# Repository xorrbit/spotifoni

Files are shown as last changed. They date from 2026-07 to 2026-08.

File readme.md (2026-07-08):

# Spotifoni

Marconi 378 antique console radio converted into a Spotify Connect speaker and Bluetooth audio sink, powered by a Raspberry Pi 3B.

## Hardware

- Raspberry Pi 3 Model B V1.2
- MAX98357A I2S mono amplifier
- Visaton FR 10 HM 4Ω full-range speaker
- 4× KY-040 rotary encoders (volume, previous, play/pause, next)
- WS2812B RGB LED sticks (8 LEDs each, behind tuner window)
- 74AHCT125 level shifter for LED data signal

See [design.md](design.md) for the full design document and [wiring.md](wiring.md) for the wiring diagrams.

## Setup

### Prerequisites

Flash **Raspberry Pi OS Lite (64-bit, Bookworm)** to a microSD card using the Raspberry Pi Imager. In the imager settings, configure:
- WiFi credentials
- SSH enabled
- Username and password

### Provision

SSH into the Pi and update the system:

```bash
sudo apt update
sudo apt upgrade -y
sudo apt install -y git
```

Clone the repo and run the setup script:

```bash
git clone https://github.com/xorrbit/spotifoni.git
cd spotifoni
sudo ./setup.sh
```

This installs all dependencies (raspotify, BlueZ, Python packages), deploys the application to `/opt/spotifoni`, configures I2S audio output, sets the hostname to `spotifoni`, and enables all systemd services.

Reboot after first run (required for the I2S DAC overlay):

```bash
sudo reboot
```

### Deploy Updates

After making changes on your dev machine, push them to the Pi without re-running the full setup:

```bash
./deploy.sh              # defaults to spotifoni.local
./deploy.sh 192.168.1.50 # or specify a host
```

This rsyncs the GPIO daemon and web app to the Pi and restarts both services.

## Usage

| What | Where |
|---|---|
| Spotify Connect | Open Spotify on any device, select **Marconi 378** as the playback device |
| Bluetooth | Pair your phone with **spotifoni** via Bluetooth settings |
| Web UI | `http://spotifoni.local/` — service status, volume, Bluetooth devices, system controls |
| SSH | `ssh pi@spotifoni.local` |

### Standalone Playback (without a phone)

Requires a Spotify Premium account.

1. Create a Spotify Developer App at https://developer.spotify.com/dashboard
2. Add `http://spotifoni.local/api/spotify/callback` as a redirect URI
3. Copy `config/spotify_api.json.example` to `config/spotify_api.json` and fill in `client_id` and `client_secret`
4. Deploy to the Pi (`./deploy.sh`)
5. Open `http://spotifoni.local/` and click **Connect Spotify Account**
6. Log in with your Spotify Premium account and authorize
7. Connect to **Marconi 378** once from any Spotify app (phone, desktop, or web player) to register the device with your account

After setup, paste any Spotify playlist, album, or track URL into the **Standalone Playback** card and press **Play**. No phone needed.

> **Tip:** To skip step 7, add `LIBRESPOT_USERNAME` and `LIBRESPOT_PASSWORD` to `/etc/raspotify/conf`. This makes the device register with Spotify automatically on boot.

### Physical Controls

- **Volume dial** — rotate to adjust volume, press to toggle mute
- **Previous dial** — press for previous track
- **Play/Pause dial** — press to toggle playback
- **Next dial** — press for next track

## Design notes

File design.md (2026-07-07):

# Spotifoni - Antique Radio Modernization — Design Document

## Project Summary

Convert a Marconi 378 antique console radio into a modern streaming audio device while preserving the original exterior appearance. The unit will support Spotify Connect (appearing as a castable speaker in the Spotify app) and function as a Bluetooth speaker for any paired phone. The four original dials will be retrofitted with rotary encoders to provide physical controls for volume, transport, and power. Configuration will happen through a local web interface.

## Design Philosophy

The guiding principle is "invisible modernity." From the outside, this should look and feel like an untouched Marconi 378. Every component choice favors small footprint, low heat, and silence. The internal layout should be tidy enough that if someone opens the back, it looks intentional — not a rat's nest.

## Hardware Architecture

### Computing Platform — Raspberry Pi 3 Model B V1.2

The brain of the system is an existing Raspberry Pi 3 Model B V1.2. It has a quad-core Cortex-A53 at 1.2 GHz, 1 GB of RAM, 2.4 GHz WiFi, and Bluetooth Classic 4.1 with A2DP support — all built in. The 40-pin GPIO header provides I2S audio output and enough GPIO pins for four rotary encoders and the WS2812 LED display. The board runs headless Raspberry Pi OS Lite with no issues.

1 GB of RAM is more than enough for the Spotify Connect + Bluetooth workload. Only a heavier approach like running a full desktop browser in kiosk mode would strain it, and that's unlikely to be needed.

The board is credit-card sized (85×56 mm), which is larger than a Pi Zero but trivially small relative to the Marconi 378's console cabinet. It draws roughly 1.5–2.5W under typical load. A passive heatsink is a good idea inside the enclosed cabinet but active cooling is not needed at these workloads.

### Audio Output — MAX98357A I2S Mono Amp

The MAX98357A breakout board takes I2S digital audio directly from the Pi's GPIO header and outputs up to 3.2W into a 4Ω speaker. The signal stays digital all the way to the amplifier chip, avoiding the Pi's noisy built-in PWM audio jack entirely. The board is tiny (roughly 25×20 mm), needs no external components, and solders to five GPIO pins: LRCLK (GPIO 19), BCLK (GPIO 18), DIN (GPIO 21), VIN (5V), and GND.

At 3.2W into the 4Ω Visaton FR 10 HM, the system will produce approximately 90 dB SPL at one meter — more than enough to fill a living room from a console radio.

### Speaker — Visaton FR 10 HM, 4Ω

The original Marconi 378 speaker is an electro-dynamic field-coil loudspeaker with a 3.2Ω voice coil. Field-coil speakers require a separate DC power supply (typically 50–100+ volts) to energize the electromagnet — without it the speaker is completely dead. Rather than rebuilding that high-voltage supply chain, the original speaker is being replaced with a modern permanent magnet driver.

The Visaton FR 10 HM is a 4-inch (10 cm) full-range driver, 4Ω impedance, rated at 20W (max 30W). It has a paper cone with moisture-resistant coating and a small whizzer tweeter cone for extended high-frequency response (95 Hz – 22 kHz). Sensitivity is 85 dB at 1W/1m. The paper cone construction gives it a warm, natural character well-suited to the "antique radio playing modern music" aesthetic.

The Marconi 378's original speaker opening is significantly larger than 4 inches. An adapter ring (flat plywood, MDF, or 3D-printed ring) with the large outer diameter matching the cabinet's existing mounting holes and a smaller inner cutout for the FR 10 HM will be fabricated. Painted black, it disappears behind the grille cloth.

The original field-coil speaker will be preserved and stored.

### Controls — KY-040 Rotary Encoders

Each of the four original dials will be mechanically coupled to a KY-040 incremental rotary encoder with a built-in push button. These output two quadrature signals (A and B channels) for rotation direction, plus a momentary switch signal when pressed. The KY-040 breakout boards include pull-up resistors, which simplifies wiring.

The mechanical coupling to the original dial shafts is the trickiest physical part of the build. Options include a flexible shaft coupler if the diameters match, a 3D-printed adapter sleeve, or mounting the encoder directly behind the dial and using a short section of silicone tubing as a flexible coupler. Standard encoder shafts are 6mm D-shaft; if the original dials are friction-fit, they may press directly onto the encoder shaft.

Control mapping:

Dial 1 (Volume): Rotate for volume up/down. Press to toggle mute or power standby. A dedicated toggle switch on the back panel for hard power on/off is the simpler alternative.

Dial 2 (Previous): Press to go to the previous track. Rotation can be mapped to seeking backward within a track, or left unmapped initially.

Dial 3 (Play/Pause): Press to toggle playback. Rotation can be mapped to switching between Spotify and Bluetooth input sources, or left unmapped initially.

Dial 4 (Next): Press to skip to the next track. Rotation can be mapped to seeking forward, or left unmapped initially.

Each encoder uses 3 GPIO pins (A, B, and switch), so four encoders need 12 GPIO pins. The Pi 3B has 26 usable GPIO pins, leaving room for the I2S bus (3 pins) and SPI for the WS2812 display (5 pins, of which only MOSI is wired).

### Status Display — WS2812B RGB LED Sticks

The tuner window is fitted with WS2812B 5050 RGB LED sticks (8 addressable LEDs per stick, chainable). These replace the original plan for individual status LEDs and provide a far more expressive display — color, brightness, and animation can all be controlled per-pixel from software.

The WS2812B protocol requires a single data line with precise timing. The Pi's SPI0 MOSI (GPIO 10) drives the data through a 74AHCT125 level shifter, which converts the Pi's 3.3V output to the 5V logic the LEDs expect. A 470Ω resistor on the data line between the level shifter output and the first LED's DIN pin prevents signal reflections. A 1000µF electrolytic capacitor across the LED power input absorbs inrush current when the LEDs switch on.

The LED sticks are powered from the same 5V rail as the rest of the system, via a separate power wire run (not through the Pi's GPIO header). At full white, 8 LEDs draw approximately 480mA; in practice, the display will run at reduced brightness and rarely approach this. The Mean Well IRM-15-5 PSU has sufficient headroom. For larger chains, a dedicated 5V supply is recommended.

The `rpi_ws281x` Python library drives the LEDs via the SPI backend. SPI0 is enabled in `/boot/firmware/config.txt`. The SPI driver claims GPIO 7, 8, 9, 10, and 11; only GPIO 10 (MOSI) is wired.

### Power Supply

The Pi 3B draws up to 2.5W under load. The MAX98357A at full volume adds up to 3.2W. LEDs and encoders add negligible draw. Total worst-case system draw is roughly 8W, so a 5V/2.5A (12.5W) supply has comfortable margin.

A Mean Well IRM-15-5 (5V, 3A, 15W) or similar enclosed AC-DC module takes mains AC directly and outputs regulated 5V. It's compact, efficient, and designed to be built into equipment. Wire the radio's power cord to the AC input side. Add a fuse (1A slow-blow) on the mains input for safety.

The original radio's power cord should be replaced with a modern 3-prong grounded cord if the chassis is metal, or at minimum a polarized 2-prong cord. Old ungrounded cloth cords are a fire and shock hazard. An IEC C14 panel-mount inlet on the back panel is the cleanest approach — it looks professional and lets you use any standard computer power cord.

## Software Architecture

The entire software stack runs on Raspberry Pi OS Lite (64-bit, Bookworm), the headless, no-desktop variant. Everything is managed through systemd services and configured either by editing files over SSH or through the web interface.

### Operating System Setup

Flash Raspberry Pi OS Lite (64-bit) to a microSD card using the Raspberry Pi Imager. Pre-configure WiFi credentials (hardcoded for now) and enable SSH in the imager's settings before first boot. On first boot the Pi will connect to the network and be accessible via SSH. No monitor or keyboard needed at any point.

### Spotify Connect — raspotify

The `raspotify` package wraps librespot (an open-source Spotify Connect client written in Rust) into a Debian package with a systemd service. Install it, configure the audio backend to use the I2S DAC via ALSA, and it just works. The radio will appear as a named device (e.g., "Marconi 378") in the Spotify app on any phone or computer on the same network. Configuration lives in `/etc/raspotify/conf` — device name, audio backend, bitrate (320 kbps for premium accounts), initial volume, and normalization settings.

Raspotify also exposes playback events (track change, play, pause, volume change) that the control daemon can subscribe to for updating the LED display.

### Bluetooth A2DP Sink

The Pi 3B's built-in Bluetooth 4.1 radio, managed by BlueZ, acts as an A2DP audio sink (a Bluetooth speaker). The setup involves enabling the Bluetooth service, setting the Pi as discoverable and pairable, configuring an agent that auto-accepts pairing, and routing the Bluetooth audio through PipeWire to the same ALSA output as Spotify.

PipeWire handles the audio routing — it can mix multiple sources and switch between them. When Spotify Connect is active, it plays Spotify. When a phone connects via Bluetooth and plays audio, it plays that instead (or mixes, depending on configuration). Priority can be configured so Spotify Connect takes over when activated, or vice versa.

Auto-pairing with a trusted device list means pairing a phone once, and it reconnects automatically whenever the radio is powered on and the phone is in range.

### GPIO Control Daemon

A small Python service using `gpiozero`. The daemon:

Reads the four rotary encoders and their push buttons via interrupts (not polling — important for responsiveness and low CPU usage). Translates encoder rotation into volume commands via `amixer` or PipeWire's `wpctl` for the volume dial. Translates button presses into MPRIS2 D-Bus commands for play/pause/next/previous — MPRIS2 is the standard Linux media player interface, and both raspotify and the Bluetooth audio player expose it, so the same button commands control whichever source is active. Drives the WS2812B RGB LED display behind the tuner window via the `rpi_ws281x` library over SPI.

This daemon runs as a systemd service that starts on boot.

### Web Configuration Interface

A lightweight Flask (Python) web server running on port 80. Accessible from any browser on the local network at `http://spotifoni.local/` (via mDNS/Avahi). It provides WiFi configuration (scan for networks, enter credentials, save to wpa_supplicant or NetworkManager), Spotify device name and audio settings, Bluetooth pairing management (list paired devices, remove pairings, toggle discoverability), system controls (restart services, reboot, shutdown safely), and a volume slider and transport controls as a web remote.

This can be very bare-bones — even a single page with a few forms. It grows naturally as features are added.

### Power Management

The Pi doesn't have a true hardware power switch — when power is cut, it just dies, which can corrupt the SD card over time. The simplest safe approach is to configure the filesystem as read-only using `overlayfs`. The root filesystem is mounted as a read-only overlay, with a writable tmpfs layer for runtime state. Configuration changes (via the web UI) temporarily remount the persistent layer as writable, write the change, and remount read-only. This is the standard approach for embedded Pi projects.

With a read-only filesystem, the back-panel power switch can just cut power directly. No shutdown sequence needed. The Pi 3B boots in about 15–20 seconds.

## Bill of Materials

| Component | Status | Approximate Cost |
|---|---|---|
| Raspberry Pi 3 Model B V1.2 | On hand | $0 |
| MAX98357A I2S Amp Breakout | Ordered | ~$6 |
| 4× KY-040 Rotary Encoders | Ordered | ~$6 |
| Visaton FR 10 HM, 4Ω | Ordered | ~$15 |
| Mean Well IRM-15-5 (5V 3A PSU) | To order | ~$10 |
| WS2812B 5050 RGB LED sticks (8 LEDs each) | Ordered | ~$4 |
| 74AHCT125 level shifter | To order | ~$2 |
| 1000µF electrolytic capacitor | To order | ~$1 |
| MicroSD card (32 GB) | To order | ~$6 |
| IEC C14 power inlet | To order | ~$3 |
| Fuse holder + 1A slow-blow fuse | To order | ~$2 |
| Speaker adapter ring material (plywood/MDF) | To fabricate | ~$3 |
| Hook-up wire, connectors, standoffs, heat shrink | To order | ~$8 |

**Total: approximately $65 CAD** (less if parts are on hand; Pi is free since it's existing stock).

## Physical Integration Plan

Strip the Marconi 378's original internals (tube chassis, original transformer, original wiring). Preserve the original field-coil speaker, the dial mechanisms, and all decorative elements. Document everything with photos before removing — reference original mounting positions.

Mount the Pi and amp board to a small piece of acrylic, plywood, or 3D-printed bracket that attaches to existing screw holes or standoffs inside the cabinet. Keep the microSD card slot accessible for reflashing.

Fabricate the speaker adapter ring: measure the original speaker cutout diameter, cut a ring from plywood or MDF with that outer diameter and a 4-inch (100mm) inner cutout for the FR 10 HM. Drill mounting holes for both the cabinet and the new speaker. Paint black.

Mount the rotary encoders behind the original dial positions. Measure the original shaft diameters and spacing, fabricate adapter couplers (3D-printed sleeves, flexible shaft couplers, or silicone tubing). If the original dials are friction-fit, they may press directly onto the 6mm encoder D-shafts.

Run the power cord through the original cord entry point. Mount the IEC C14 inlet on the back panel. Position the PSU module away from the audio components to minimize electrical noise.

Route wiring neatly with zip ties or cable lacing. Keep mains AC wiring physically separated from low-voltage DC signal wiring. Use JST connectors for serviceability so components can be disconnected without desoldering.

## Build Roadmap

**Bench validation** — Get the Pi 3B running headless with SSH access. Install raspotify, confirm Spotify Connect works with the FR 10 HM connected via the MAX98357A. Set up Bluetooth A2DP sink and confirm phone audio plays through the same output. Wire up all four encoders and the WS2812B LED display on a breadboard. Write the full GPIO control daemon with MPRIS2 integration. Set up PipeWire for audio source switching. Build the basic web config interface. Configure read-only filesystem.

**Physical integration** — Strip the radio. Fabricate the speaker adapter ring and encoder mounts. Build the internal component bracket. Transfer everything from the breadboard into the cabinet. Solder permanent connections or crimp JST connectors. Test everything in-cabinet, adjust LED brightness and encoder feel.

**Polish** — Tune the audio (EQ settings in PipeWire to compensate for the speaker and cabinet characteristics). Refine the web interface. Set up mDNS so the web UI is reachable at `marconi378.local`. Final cable management and cleanup.

## Future Upgrades

### Standalone Spotify (Software Only)

When ready to move beyond Spotify Connect to fully standalone playback (power on, press play, music plays without touching a phone), the hardware is already in place. Replace raspotify with `spotifyd`, which is a more feature-rich Spotify client that can be controlled programmatically. Write a control layer that uses the Spotify Web API (with an OAuth token stored on the device) to manage playback — load a saved playlist, resume last session, skip tracks. The rotary encoders gain new roles: one dial scrolls through playlists, another navigates tracks within a playlist. An SSD1306 OLED displays track info and playlist names. A phone is only needed for the initial OAuth login. The Pi 3B's 1 GB of RAM handles this comfortably.

### Board Swap

If more compute power is ever needed (unlikely for audio), the Pi 3B can be swapped for a Pi 4B or Pi 5 with no other hardware changes — same 40-pin GPIO header, same I2S pinout, same software stack. For an open-source hardware path, the BeaglePlay ($99, OSHW-certified, 2 GB RAM, 16 GB eMMC) is the strongest alternative, though it requires a USB Bluetooth dongle for A2DP since it only has BLE onboard.

### Audio Quality Upgrade

If the MAX98357A's audio quality ever feels limiting, swap it for a PCM5102A I2S DAC breakout (line-level output) feeding a separate higher-quality amplifier. The I2S pins on the Pi are the same, so it's a drop-in change on the digital side.

### Original Speaker Restoration

The Marconi 378's field-coil speaker could be brought back to life by building a DC power supply for the field coil (measure its resistance, provide appropriate voltage and current) and adding a 1Ω series resistor to bring the 3.2Ω voice coil impedance up to 4.2Ω for the MAX98357A. This is a rewarding side project for a rainy weekend but not required for the system to work.

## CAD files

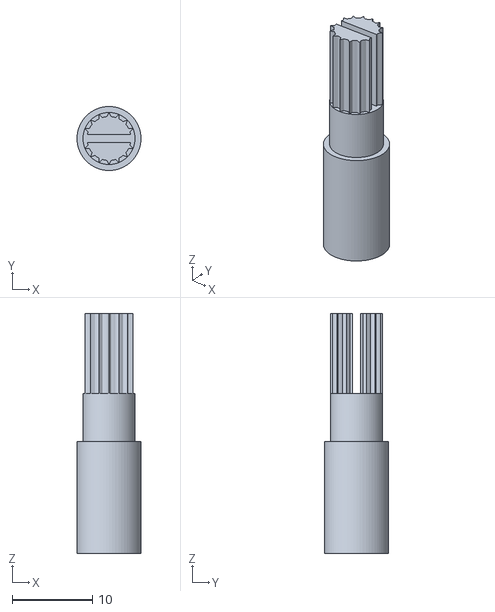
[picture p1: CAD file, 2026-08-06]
knob extender v3.stl
8.00 x 8.00 x 30.0

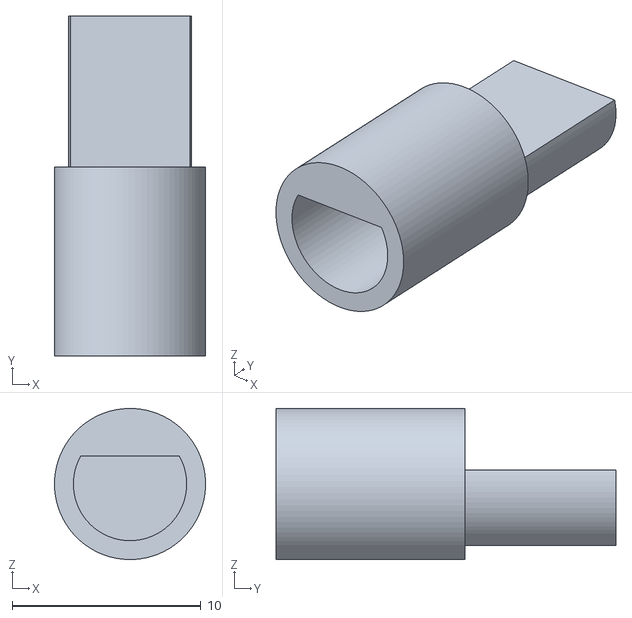
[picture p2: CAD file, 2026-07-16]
rotary encoder knob adapter.stl
8.00 x 18.0 x 8.00

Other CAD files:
knob extender v2.stl
knob extender.stl

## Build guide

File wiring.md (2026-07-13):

# Spotifoni Wiring

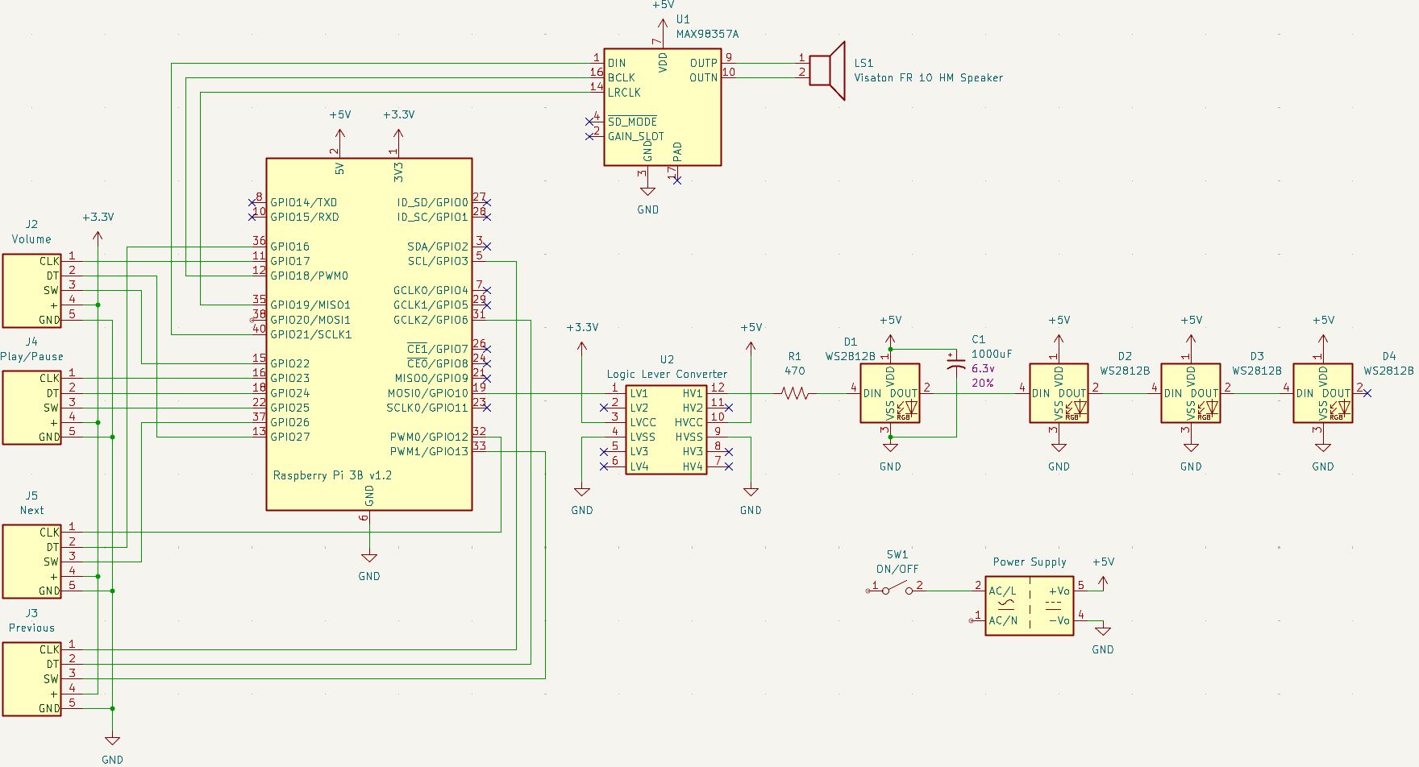
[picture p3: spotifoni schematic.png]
Schematic


## GPIO Allocation

| Function | GPIO Pins | Header Pins |
|---|---|---|
| Encoder 1 — Volume | GPIO 17, 27, 22 | 11, 13, 15 |
| Encoder 2 — Previous | GPIO 5, 6, 13 | 29, 31, 33 |
| Encoder 3 — Play/Pause | GPIO 23, 24, 25 | 16, 18, 22 |
| Encoder 4 — Next | GPIO 12, 16, 26 | 32, 36, 37 |
| WS2812B LED data | GPIO 10 | 19 |
| SPI0 (reserved by driver) | GPIO 7, 8, 9, 11 | 26, 24, 21, 23 |
| *I²S bus (allocated)* | GPIO 18, 19, 21 | 12, 35, 40 |

## I²S Amplifier (U1 — MAX98357A)

| Pi Header | Function | MAX98357A |
|---|---|---|
| Pin 2 | 5V Power | VDD |
| Pin 6 | Ground | GND |
| Pin 12 | GPIO 18 · PCM_CLK | BCLK |
| Pin 35 | GPIO 19 · PCM_FS | LRCLK |
| Pin 40 | GPIO 21 · PCM_DOUT | DIN |

Speaker output (OUTP/OUTN) connects to a Visaton FR 10 HM 8Ω speaker.

## WS2812B LED Display (D1–D4)

The LED data signal passes through a logic level converter (U2) to shift GPIO 10's 3.3V output to 5V. A 1kΩ resistor (R1) sits between the level converter output and the first LED's DIN pin.

| From | To | Notes |
|---|---|---|
| Pi GPIO 10 (Pin 19) | U2 LV1 (pin 1) | 3.3V data from SPI MOSI |
| U2 HV1 (pin 12) | R1 (470Ω) → D1 WS2812B DIN | 5V level-shifted data out |
| Pi 3.3V (Pin 1) | U2 LVCC (pin 3) | Level converter low-side supply |
| 5V rail | U2 HVCC (pin 9) | Level converter high-side supply |
| GND | U2 LVSS (pin 5), U2 HVSS (pin 4) | Common ground |
| 5V rail | C1 1000µF cap (+) → D1 VDD | Bulk decoupling for LED chain |
| GND | C1 1000µF cap (−) → D1 VSS | |

LEDs are daisy-chained: D1 DOUT → D2 DIN → D3 DIN → D4 DIN. Each LED's VDD connects to 5V and VSS to GND.

## Encoder Wiring (J2–J5)

All four encoders use the same wiring pattern. Connect each encoder's `+` pin to **3.3V** and `GND` to ground. The CLK, DT, and SW pins connect to the GPIO pins listed in the allocation table above.

| KY-040 Pin | Connects To | Notes |
|---|---|---|
| + | Pi 3.3V (Pin 1) | **Not 5V** — Pi GPIOs are 3.3V only |
| GND | Pi GND | Shared ground rail |
| CLK (A) | GPIO per table | Quadrature channel A |
| DT (B) | GPIO per table | Quadrature channel B |
| SW | GPIO per table | Push button (use internal pull-up) |

## Power Supply

An AC/DC power supply provides 5V to the system through an on/off switch (SW1). The Pi, MAX98357A, level converter high side, and WS2812B LEDs all run from this 5V rail.

## Setup Notes

1. Enable I²S output: add `dtoverlay=hifiberry-dac` to `/boot/firmware/config.txt` and reboot.
2. Enable SPI: add `dtparam=spi=on` to `/boot/firmware/config.txt` and reboot.
3. Test audio: `speaker-test -D hw:0 -t sine`.
4. Connect encoders to **3.3V (Pin 1), not 5V**. Pi GPIO pins are 3.3V-tolerant only — 5V will damage them.
5. The KY-040 has onboard 10kΩ pull-ups on CLK and DT. No external resistors needed. The SW pin uses the Pi's internal pull-up (configured in software).
6. The SPI driver claims GPIO 7, 8, 9, 10, 11 — only GPIO 10 (MOSI) is physically wired.
7. The 470Ω resistor goes between the level converter output and the first LED's DIN pin to protect against voltage spikes during power-on.
8. The 1000µF electrolytic capacitor (6.3V, 20%) goes across the first LED's VDD and GND, as close to D1 as possible.
9. Chain additional LEDs by connecting DOUT of one module to DIN of the next. Update `LED_COUNT` in software to match.

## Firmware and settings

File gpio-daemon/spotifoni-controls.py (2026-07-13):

#!/usr/bin/env python3
"""Spotifoni GPIO control daemon — reads four rotary encoders, controls volume and transport."""

import os
import signal
import subprocess
import sys
import threading
import time
import urllib.request

sys.path.insert(0, os.path.dirname(os.path.abspath(__file__)))
import leds

try:
    from gpiozero import RotaryEncoder, Button
except ImportError:
    print("gpiozero not available — install with: sudo apt install python3-gpiozero")
    sys.exit(1)

VOLUME_CLK = 17
VOLUME_DT = 27
VOLUME_SW = 22

PREV_CLK = 5
PREV_DT = 6
PREV_SW = 13

PLAY_CLK = 23
PLAY_DT = 24
PLAY_SW = 25

NEXT_CLK = 12
NEXT_DT = 16
NEXT_SW = 26

WEB_API = "http://127.0.0.1"

VOLUME_STEP = 2
VOLUME_TICKS_PER_STEP = 1
DEBOUNCE_SEC = 0.3

last_press = {"volume": 0, "prev": 0, "play": 0, "next": 0}
_vol_accum = 0
_vol_pending = 0
_vol_timer = None


def _web_post(path, data=None):
    import json as _json
    body = _json.dumps(data).encode() if data else b""
    headers = {"Content-Type": "application/json"} if data else {}
    req = urllib.request.Request(
        f"{WEB_API}{path}",
        data=body,
        headers=headers,
        method="POST",
    )
    try:
        urllib.request.urlopen(req, timeout=5)
    except Exception:
        pass


def _flush_volume():
    global _vol_pending
    if _vol_pending != 0:
        _web_post("/api/volume", {"delta": _vol_pending})
        _vol_pending = 0


def set_volume(delta):
    global _vol_pending, _vol_timer
    _vol_pending += delta
    if _vol_timer is not None:
        _vol_timer.cancel()
    _vol_timer = threading.Timer(0.2, _flush_volume)
    _vol_timer.start()


def transport_command(action):
    _web_post(f"/api/transport/{action}")


def toggle_mute():
    _web_post("/api/volume/mute")


def debounced(key):
    now = time.monotonic()
    if now - last_press[key] < DEBOUNCE_SEC:
        return False
    last_press[key] = now
    return True


def on_volume_rotate(encoder):
    global _vol_accum
    _vol_accum += encoder.steps
    encoder.steps = 0
    if abs(_vol_accum) >= VOLUME_TICKS_PER_STEP:
        set_volume(VOLUME_STEP if _vol_accum > 0 else -VOLUME_STEP)
        _vol_accum = 0


def on_volume_press():
    if debounced("volume"):
        toggle_mute()


def on_prev_press():
    if debounced("prev"):
        transport_command("previous")


def on_play_press():
    if debounced("play"):
        transport_command("play-pause")


def on_next_press():
    if debounced("next"):
        transport_command("next")


def main():
    vol_encoder = RotaryEncoder(VOLUME_CLK, VOLUME_DT, max_steps=0, wrap=False)
    vol_button = Button(VOLUME_SW, pull_up=True, bounce_time=0.05)
    vol_encoder.when_rotated = lambda: on_volume_rotate(vol_encoder)
    vol_button.when_pressed = on_volume_press

    prev_encoder = RotaryEncoder(PREV_CLK, PREV_DT, max_steps=0, wrap=False)
    prev_button = Button(PREV_SW, pull_up=True, bounce_time=0.05)
    prev_button.when_pressed = on_prev_press

    play_encoder = RotaryEncoder(PLAY_CLK, PLAY_DT, max_steps=0, wrap=False)
    play_button = Button(PLAY_SW, pull_up=True, bounce_time=0.05)
    play_button.when_pressed = on_play_press

    next_encoder = RotaryEncoder(NEXT_CLK, NEXT_DT, max_steps=0, wrap=False)
    next_button = Button(NEXT_SW, pull_up=True, bounce_time=0.05)
    next_button.when_pressed = on_next_press

    led_ok = leds.init()
    if led_ok:
        leds.set_all(40, 20, 0)
        leds.show()

    print("Spotifoni controls active:")
    print(f"  Volume:     GPIO {VOLUME_CLK}/{VOLUME_DT}/{VOLUME_SW}")
    print(f"  Previous:   GPIO {PREV_CLK}/{PREV_DT}/{PREV_SW}")
    print(f"  Play/Pause: GPIO {PLAY_CLK}/{PLAY_DT}/{PLAY_SW}")
    print(f"  Next:       GPIO {NEXT_CLK}/{NEXT_DT}/{NEXT_SW}")
    print(f"  WS2812:     {'active' if led_ok else 'not available'}")

    stop = threading.Event()
    signal.signal(signal.SIGTERM, lambda *_: stop.set())
    signal.signal(signal.SIGINT, lambda *_: stop.set())
    stop.wait()
    leds.clear()
    print("Shutting down.")


if __name__ == "__main__":
    main()

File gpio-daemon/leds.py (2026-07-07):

"""WS2812B LED strip driver for Spotifoni."""

_strip = None

SPI_PIN = 10
DEFAULT_COUNT = 8
DEFAULT_BRIGHTNESS = 50


def init(num_leds=DEFAULT_COUNT, brightness=DEFAULT_BRIGHTNESS):
    global _strip
    try:
        from rpi_ws281x import PixelStrip, ws
        _strip = PixelStrip(num_leds, SPI_PIN,
                            strip_type=ws.WS2812_STRIP,
                            brightness=brightness)
        _strip.begin()
        return True
    except (ImportError, RuntimeError) as e:
        print(f"WS2812 init skipped: {e}")
        _strip = None
        return False


def set_pixel(n, r, g, b):
    if _strip and 0 <= n < _strip.numPixels():
        _strip.setPixelColorRGB(n, r, g, b)


def set_all(r, g, b):
    if _strip:
        for i in range(_strip.numPixels()):
            _strip.setPixelColorRGB(i, r, g, b)


def clear():
    set_all(0, 0, 0)
    show()


def show():
    if _strip:
        _strip.show()

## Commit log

2026-07-06 Add software stack: provisioning script, GPIO daemon, web UI, and wiring docs
    Setup script provisions a fresh Pi OS Lite install with raspotify, Bluetooth
    A2DP, the GPIO control daemon, and the Flask web config interface. Deploy
    script handles quick code updates over SSH.
2026-07-06 Add audio output switching and dev mode
    Web UI can toggle between headphone jack and I2S DAC — rewrites
    asound.conf and restarts raspotify. Both outputs coexist (onboard
    audio no longer disabled). Dev mode auto-detects non-Pi hosts and
    serves mock data on port 8080. Added pre-provision steps to readme.
2026-07-07 Add rotary encoder controls, WS2812B LED support, and flatten project structure
    Wire up all four rotary encoders (volume/mute, previous, play/pause, next)
    with MPRIS2 transport control via D-Bus. Add WS2812B RGB LED strip driver
    over SPI with 74AHCT125 level shifter circuit. Replace individual status
    LEDs with addressable LED sticks behind the tuner window. Add web UI
    transport controls and mute toggle. Remove phase-based organization and
    consolidate future/planned items into a single design doc section.
    [leds.py, spotifoni-controls.py]
2026-07-07 Remove phase1-wiring.svg and update wiring diagram
2026-07-08 Add standalone Spotify playback via Web API
    Adds a "Standalone Playback" card to the web UI where users can paste a
    Spotify playlist, album, or track URL to start playback without needing
    a phone. Uses the Spotify Web API with OAuth2 to control the existing
    raspotify device programmatically.
2026-07-13 Replace SVG wiring diagrams with KiCad schematic
2026-07-13 Update wiring docs and schematic to match current design
2026-07-13 Route volume and transport controls through Spotify Web API
    Volume control was using amixer which had no effect because the
    MAX98357A has no hardware mixer. Transport controls used D-Bus MPRIS2
    which raspotify doesn't expose. Both now go through the Spotify Web
    API via spotipy.
    - Add ALSA softvol plugin to asound.conf for fallback volume control
    - Add Spotify Web API functions for volume, mute, play/pause, next, prev
    - GPIO daemon routes all controls through the Flask web API
    - Debounce encoder volume ticks to avoid Spotify rate limiting
    - Add encoder diagnostic script (test-encoder.py)
    [spotifoni-controls.py, test-encoder.py]
2026-07-16 Added rotary encoder knob adapter
    [rotary encoder knob adapter.stl]
2026-08-06 another knob extender
    [knob extender.stl]
2026-08-06 knob extender v2
    [knob extender v2.stl]
